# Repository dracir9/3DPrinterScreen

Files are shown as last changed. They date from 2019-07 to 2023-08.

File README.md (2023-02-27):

# 3D Printer Screen
3D Printer Screen is a 3d printer controller project based arround ESP32. The purpose of this project is to add wireless connectivity to the printer and simplify its operation through LCD and touchscreen interfaces.

**_Early development_**

## Hardware Prerequisites
This code is now targeted for use in a custom designed board which has an ESP32-S3 microcontroller, USB interface, micro SD card slot and 40-pin LCD connector. The design files in KiCad can be found here.

Follow this reference shcematic if you want to build your own board or need a pinout reference.

Pay attention to these components requirements for the project to work:
- TFT LCD display compatible with [TFT_eSPI](https://github.com/Bodmer/TFT_eSPI) library. The current version of the sowftware uses an 8-bit parallel bus but SPI can also be used to control the LCD.
- ESP32-S3 Wroom-1 with at least 8MB of SPIRAM (ESP32-S3 Wroom-2 can also be used)
- EFM8BB10F8G microcontroller

## Current features
 - [x] SD card browser
 - [x] SD card printing
 - [x] Gcode preview
 
## Screenshots
#### Main screen
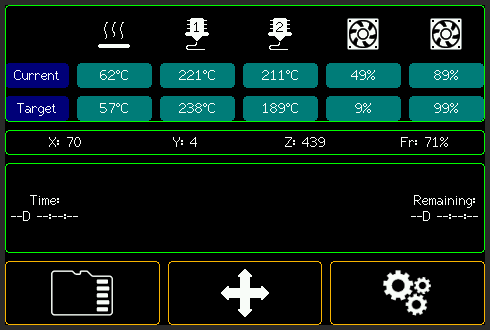
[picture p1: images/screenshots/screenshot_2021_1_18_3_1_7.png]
info

#### SD card browser
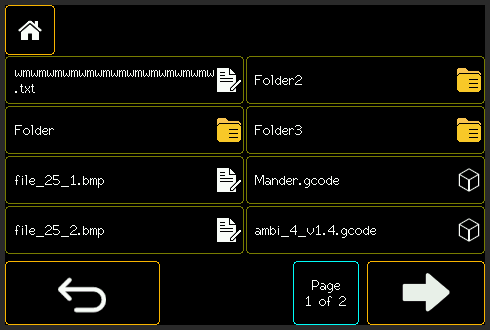
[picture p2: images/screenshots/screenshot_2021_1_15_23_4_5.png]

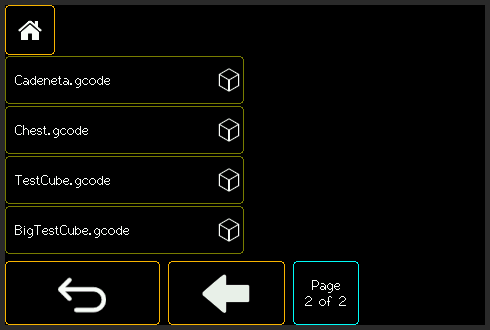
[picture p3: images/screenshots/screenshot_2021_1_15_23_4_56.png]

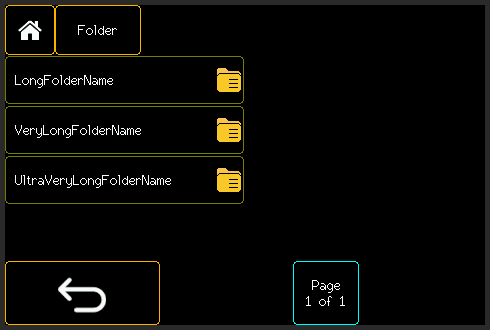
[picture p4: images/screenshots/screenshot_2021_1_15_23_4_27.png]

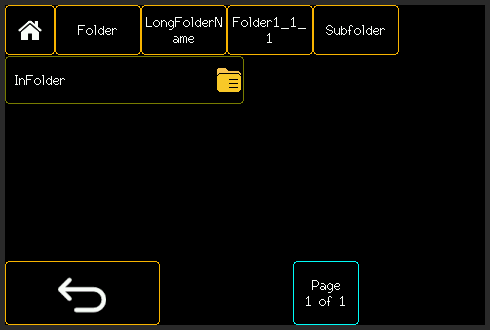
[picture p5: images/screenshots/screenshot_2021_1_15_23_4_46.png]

#### Gcode preview
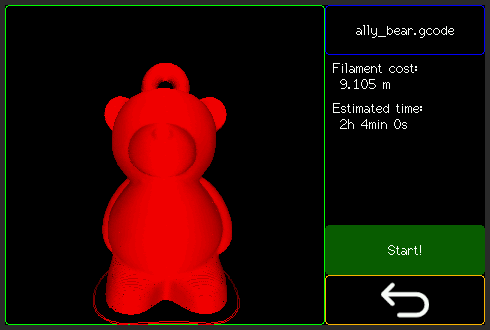
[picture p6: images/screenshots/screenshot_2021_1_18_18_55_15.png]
 Based on [this design](https://www.thingiverse.com/thing:2508515)
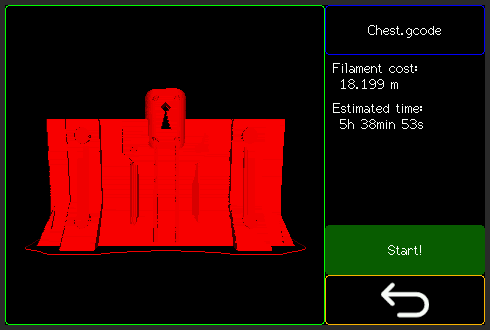
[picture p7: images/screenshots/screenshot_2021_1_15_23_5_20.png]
 Based on [this design](https://www.thingiverse.com/thing:2914080)
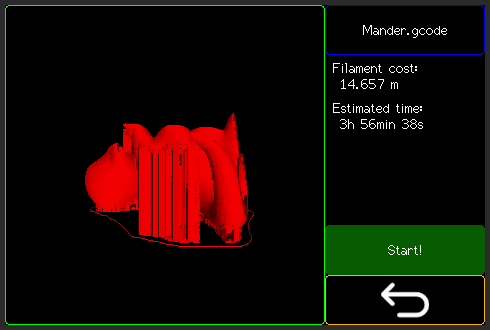
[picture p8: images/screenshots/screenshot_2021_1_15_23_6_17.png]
 Based on [this design](https://www.thingiverse.com/thing:826836)
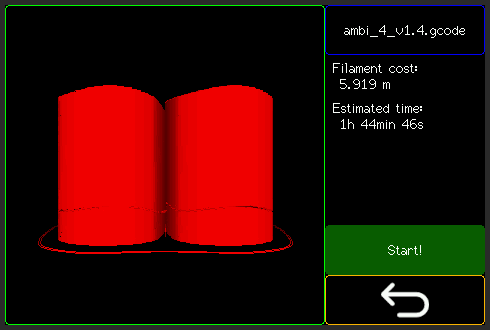
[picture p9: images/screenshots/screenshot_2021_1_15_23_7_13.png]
 Based on [this design](https://www.thingiverse.com/thing:1657791)
 
## Planned features
 - [ ] Movement, temperature, settings, file selection, etc. menus
 - [ ] SD card printing
 - [ ] WiFi printing

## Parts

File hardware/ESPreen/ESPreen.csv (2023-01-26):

Source: | D:\Users\Ricard\Documents\GitHub\3DPrinterScreen\hardware\ESPreen\ESPreen.kicad_sch
Date: | 21/01/2023 11:14:19
Tool: | Eeschema (6.0.10)
Generator: | C:\Program Files\KiCad\6.0\bin\scripting\plugins/bom_csv_grouped_by_value_with_fp.py
Component Count: | 52
Ref | Qnty | Value | Cmp name | Footprint | Description | Vendor
C1, C7, C9, C11, C13, C16, | 6 | 10uF | C | Capacitor_SMD:C_0603_1608Metric_Pad1.08x0.95mm_HandSolder | Unpolarized capacitor
C2, | 1 | 4.7uF | C | Capacitor_SMD:C_0603_1608Metric_Pad1.08x0.95mm_HandSolder | Unpolarized capacitor
C3, C4, C6, C8, C10, C15, | 6 | 100nF | C | Capacitor_SMD:C_0603_1608Metric_Pad1.08x0.95mm_HandSolder | Unpolarized capacitor
C5, C12, C14, | 3 | 1uF | C | Capacitor_SMD:C_0603_1608Metric_Pad1.08x0.95mm_HandSolder | Unpolarized capacitor
D1, D2, | 2 | LED | LED | LED_SMD:LED_0603_1608Metric_Pad1.05x0.95mm_HandSolder | Light emitting diode
D3, D4, D5, D6, D7, D8, | 6 | ESD9B3.3ST5G | ESD9B3.3ST5G | Diode_SMD:D_SOD-523 | ESD protection diode, 3.3Vrwm, SOD-923
IC1, | 1 | ESP32-S3-WROOM-1 | ESP32-S3-WROOM-1 | RF_Module:ESP32-S3-WROOM-1
J1, | 1 | USB_A | USB_A | Connector_USB:USB_A_Molex_67643_Horizontal | USB Type A connector
J2, | 1 | Conn_02x07_Odd_Even | Conn_02x07_Odd_Even | Connector_PinHeader_2.54mm:PinHeader_2x07_P2.54mm_Vertical | Generic connector, double row, 02x07, odd/even pin numbering scheme (row 1 odd numbers, row 2 even numbers), script generated (kicad-library-utils/schlib/autogen/connector/)
J3, J6, | 2 | Conn_02x03_Odd_Even | Conn_02x03_Odd_Even | Connector_PinHeader_1.27mm+:PinHeader_2x03_P1.27mm_Vertical_Shrouded | Generic connector, double row, 02x03, odd/even pin numbering scheme (row 1 odd numbers, row 2 even numbers), script generated (kicad-library-utils/schlib/autogen/connector/)
J4, | 1 | Conn_02x05_Odd_Even | Conn_02x05_Odd_Even | Connector_PinHeader_2.54mm:PinHeader_2x05_P2.54mm_Vertical | Generic connector, double row, 02x05, odd/even pin numbering scheme (row 1 odd numbers, row 2 even numbers), script generated (kicad-library-utils/schlib/autogen/connector/)
J5, | 1 | Micro_SD_Card_Det | Micro_SD_Card_Det | Connector_Card+:microSD_XunPu-F115 | Micro SD Card Socket with card detection pins
J7, | 1 | Conn_01x04 | Conn_01x04 | Connector_Molex+:Molex_SL_70553-0004_1x04_P2.54mm_Horizontal | Generic connector, single row, 01x04, script generated (kicad-library-utils/schlib/autogen/connector/)
Q1, | 1 | 2N7002 | 2N7002 | Package_TO_SOT_SMD:SOT-23 | 0.115A Id, 60V Vds, N-Channel MOSFET, SOT-23
R1, R2, | 2 | 1k | R | Resistor_SMD:R_0603_1608Metric_Pad0.98x0.95mm_HandSolder | Resistor
R3, R4, R5, R6, R7, R8, R9, R10, R12, | 9 | 10k | R | Resistor_SMD:R_0603_1608Metric_Pad0.98x0.95mm_HandSolder | Resistor
R11, | 1 | 470 | R | Resistor_SMD:R_0603_1608Metric_Pad0.98x0.95mm_HandSolder | Resistor
R13, | 1 | 0 | R | Resistor_SMD:R_0603_1608Metric_Pad0.98x0.95mm_HandSolder | Resistor
TP1, TP2, | 2 | TestPoint | TestPoint | TestPoint:TestPoint_Pad_D1.0mm | test point
U1, | 1 | LD1117S33TR_SOT223 | LD1117S33TR_SOT223 | Package_TO_SOT_SMD:SOT-223-3_TabPin2 | 800mA Fixed Low Drop Positive Voltage Regulator, Fixed Output 3.3V, SOT-223
U2, | 1 | EFM8BB10F8G-A-SOIC16 | EFM8BB10F8G-A-SOIC16 | Package_SO:SOIC-16_3.9x9.9mm_P1.27mm | 8051-compatible microcontroller, 25 MHz, 2.2 to 3.6V, 8K flash, 512B RAM, -40 to +85 C, SOIC16
U3, | 1 | USBLC6-2SC6 | USBLC6-2SC6 | Package_TO_SOT_SMD:SOT-23-6 | Very low capacitance ESD protection diode, 2 data-line, SOT-23-6
U4, | 1 | TFT43-RTP | TFT43-RTP | Connector_FFC-FPC+:Jushuo-AFC07-S40ECA-00_1x40-1MP_P0.50mm_Horizontal | 40 pin TFT-LCD Connector with resistive touch screen

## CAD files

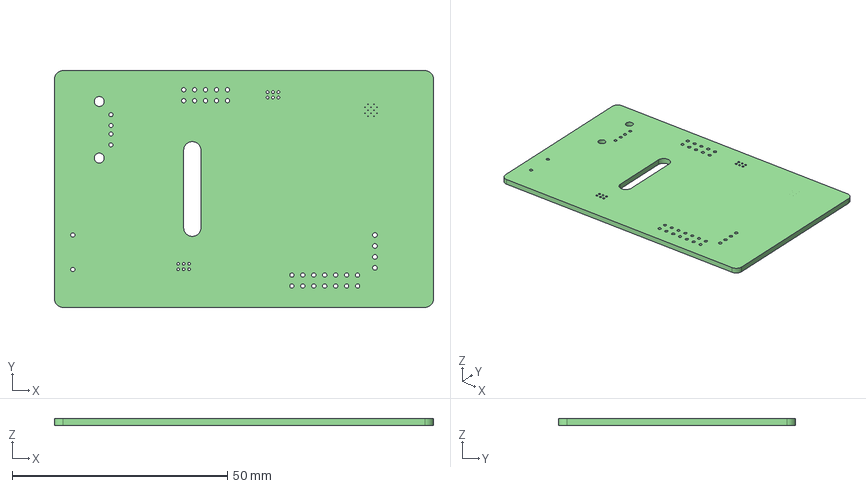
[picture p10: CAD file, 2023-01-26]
hardware/ESPreen/ESPreen.step
88.0 x 55.0 x 1.60 mm

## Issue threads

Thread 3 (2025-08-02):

what is the purpose of EFM8BB10F8G

ekaggrat, 2025-08-02:
why cant this firmware be used on a readily available esp32 board with a built in lcd and a sd card. What is the purpose of the extra microcontroller . Just asking. great project though. Is the custom pcb available somewhere?

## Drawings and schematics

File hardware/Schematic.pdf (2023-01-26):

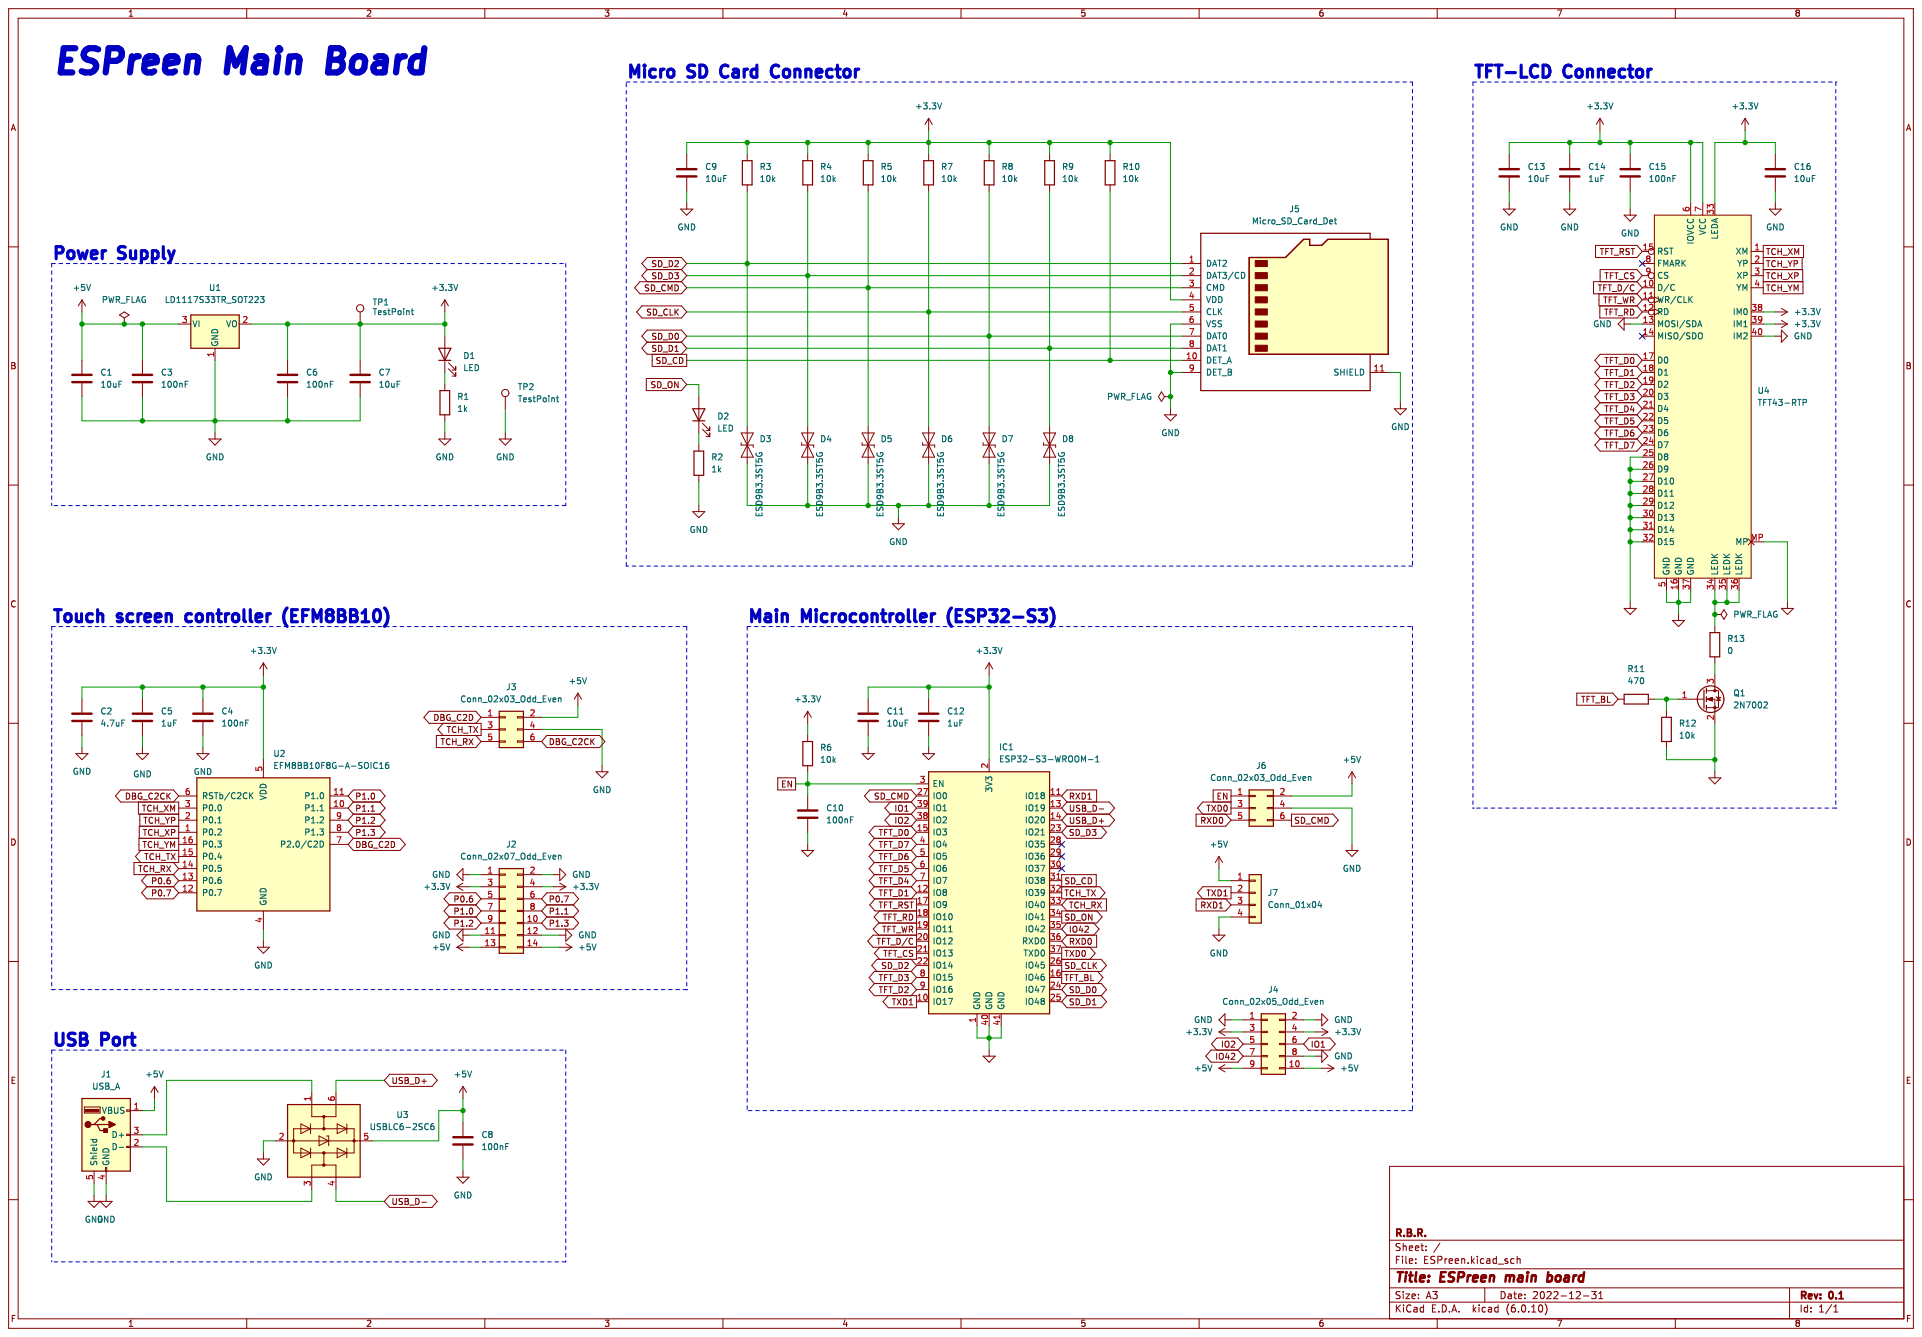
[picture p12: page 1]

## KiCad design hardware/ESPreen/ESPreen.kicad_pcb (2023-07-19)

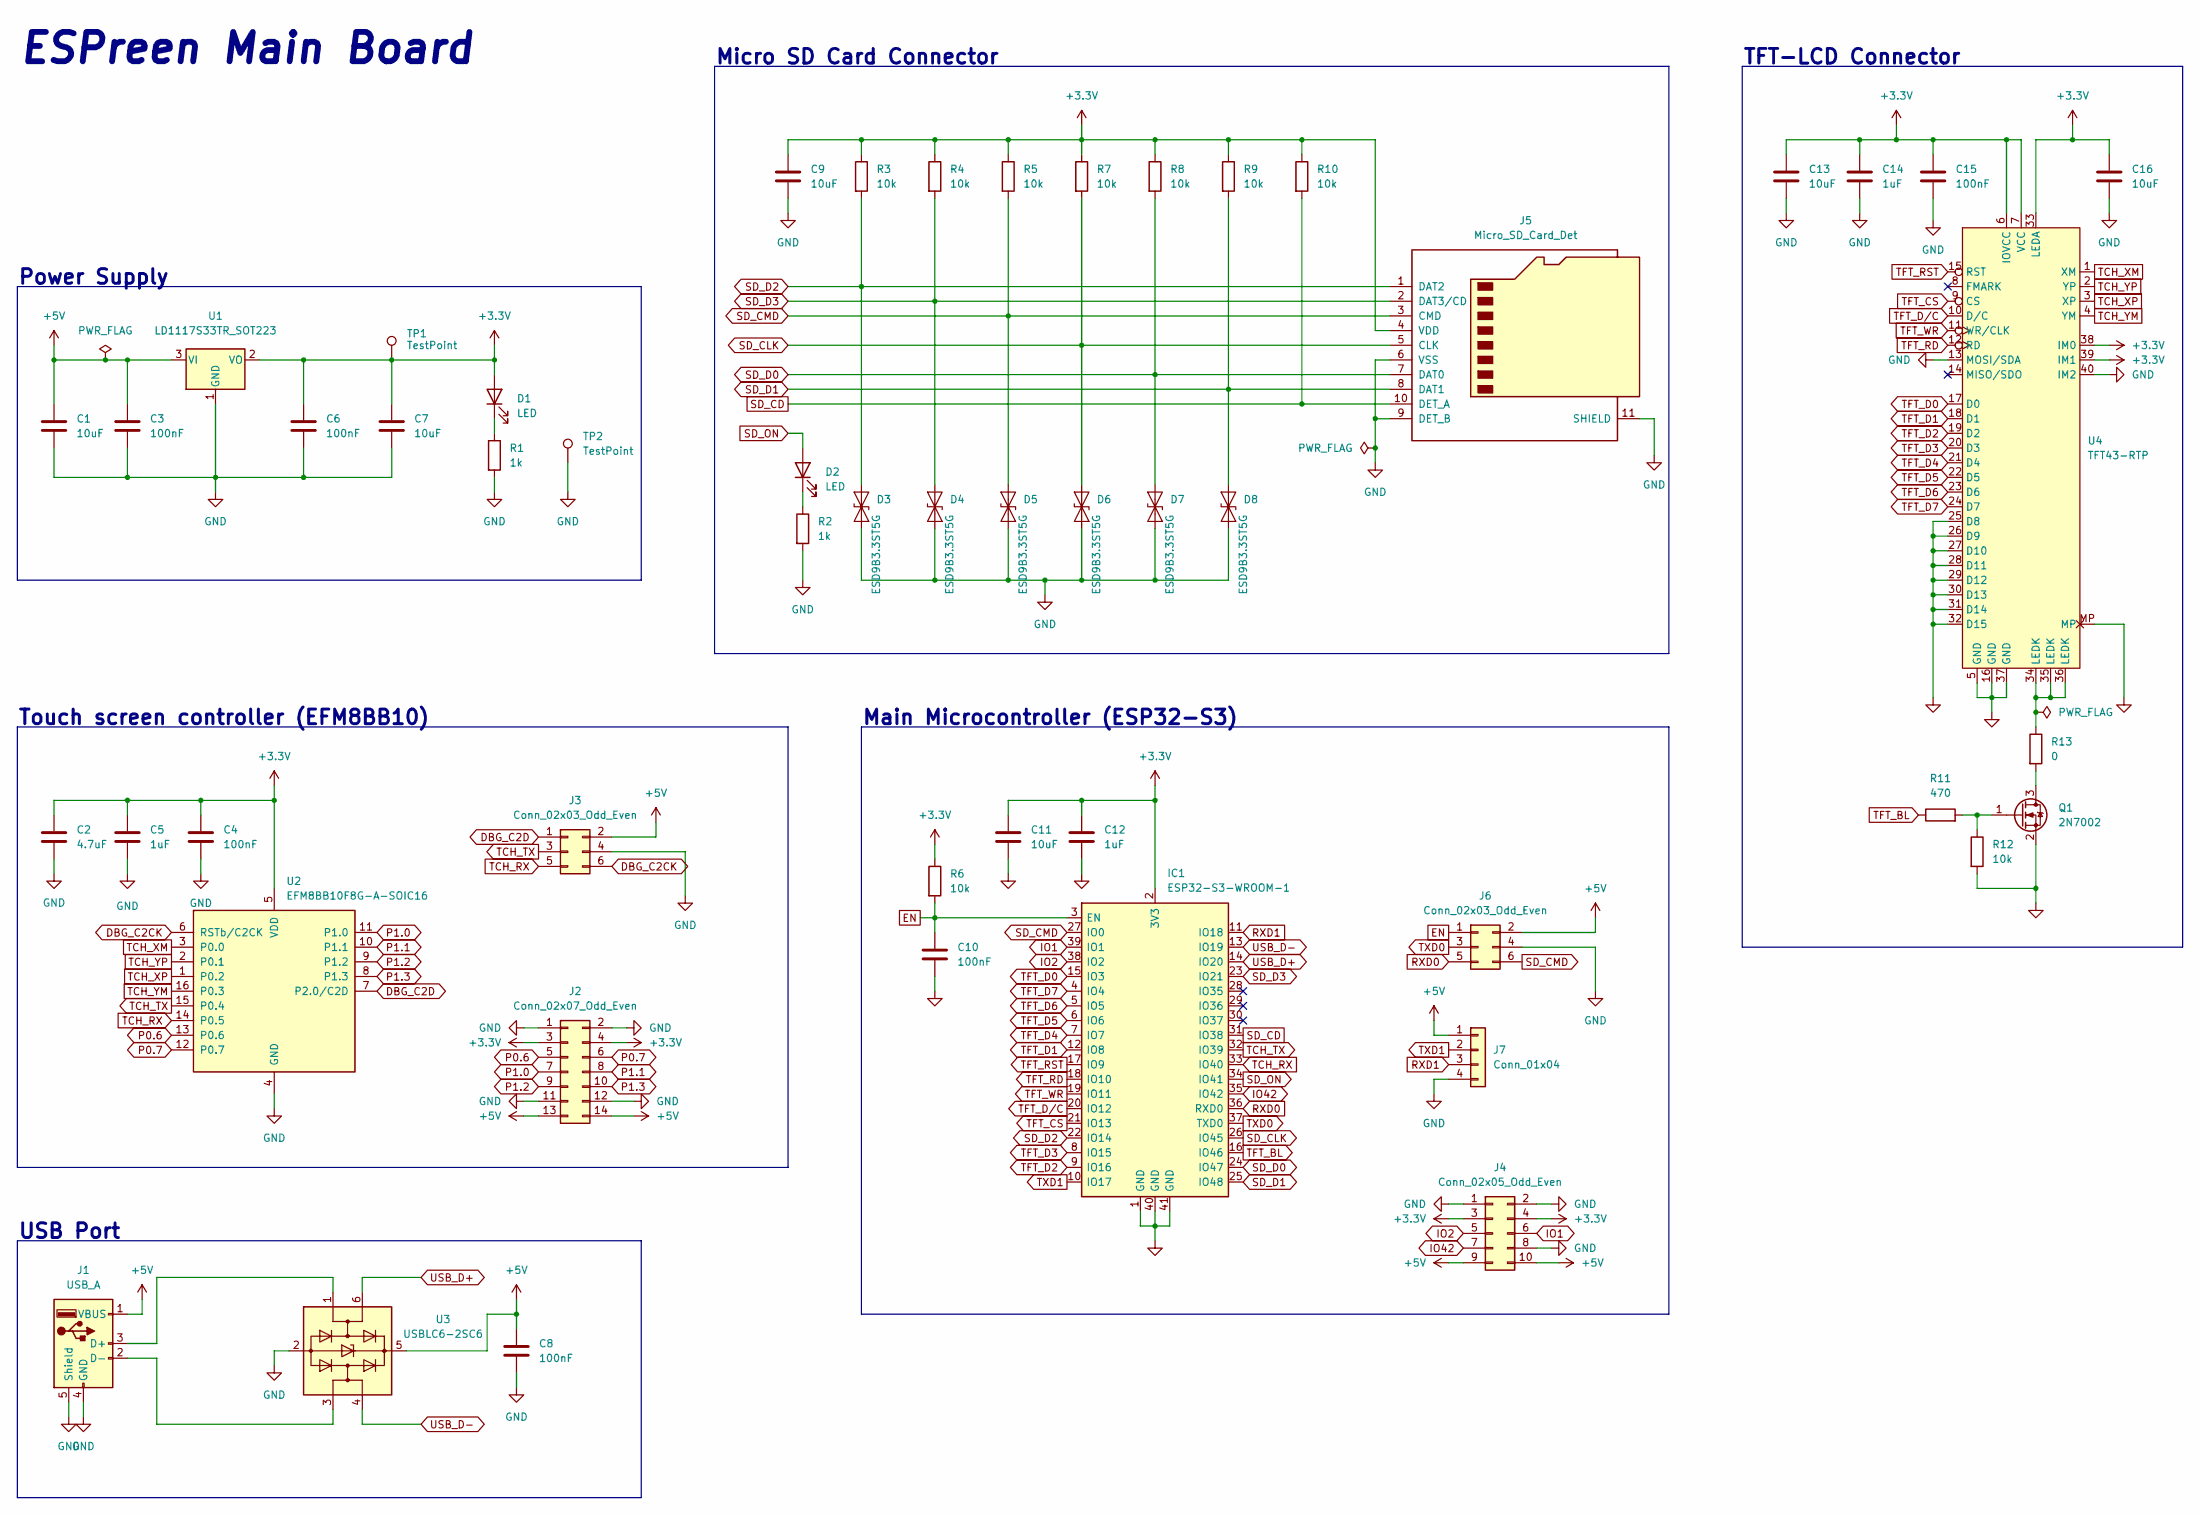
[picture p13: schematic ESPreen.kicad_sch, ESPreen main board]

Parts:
C1, C7, C9, C11, C13, C16: 10uF; C_0603_1608Metric_Pad1.08x0.95mm_HandSolder
C2: 4.7uF; C_0603_1608Metric_Pad1.08x0.95mm_HandSolder
C3, C4, C6, C8, C10, C15: 100nF; C_0603_1608Metric_Pad1.08x0.95mm_HandSolder
C5, C12, C14: 1uF; C_0603_1608Metric_Pad1.08x0.95mm_HandSolder
D1, D2: LED; LED_0603_1608Metric_Pad1.05x0.95mm_HandSolder
D3, D4, D5, D6, D7, D8: ESD9B3.3ST5G; D_SOD-523
IC1: ESP32-S3-WROOM-1; Manufacturer_Part_Number ESP32-S3-WROOM-1; Mouser Part Number 356-EP32S3WROOM1
J1: USB_A; USB_A_Molex_67643_Horizontal
J2: Conn_02x07_Odd_Even; PinHeader_2x07_P2.54mm_Vertical
J3, J6: Conn_02x03_Odd_Even; PinHeader_2x03_P1.27mm_Vertical_Shrouded
J4: Conn_02x05_Odd_Even; PinHeader_2x05_P2.54mm_Vertical
J5: Micro_SD_Card_Det; microSD_XunPu-F115
J7: Conn_01x04; Molex_SL_70553-0004_1x04_P2.54mm_Horizontal
Q1: 2N7002; SOT-23
R1, R2: 1k; R_0603_1608Metric_Pad0.98x0.95mm_HandSolder
R3, R4, R5, R6, R7, R8, R9, R10, R12: 10k; R_0603_1608Metric_Pad0.98x0.95mm_HandSolder
R11: 470; R_0603_1608Metric_Pad0.98x0.95mm_HandSolder
R13: 0; R_0603_1608Metric_Pad0.98x0.95mm_HandSolder
TP1, TP2: TestPoint; TestPoint_Pad_D1.0mm
U1: LD1117S33TR_SOT223; SOT-223-3_TabPin2
U2: EFM8BB10F8G-A-SOIC16; SOIC-16_3.9x9.9mm_P1.27mm
U3: USBLC6-2SC6; SOT-23-6
U4: TFT43-RTP; Jushuo-AFC07-S40ECA-00_1x40-1MP_P0.50mm_Horizontal

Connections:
+3.3V: C2.1, C4.1, C5.1, C6.1, C7.1, C9.1, C11.1, C12.1, C13.1, C14.1, C15.1, C16.1, D1.2 (A), IC1.2 (3V3), J2.3, J2.4, J4.3, J4.4, J5.4 (VDD), R3.1, R4.1, R5.1, R6.1, R7.1, R8.1, R9.1, R10.1, TP1.1, U1.2 (VO), U2.5 (VDD), U4.6 (IOVCC), U4.7 (VCC), U4.33 (LEDA), U4.38 (IM0), U4.39 (IM1)
+5V: C1.1, C3.1, C8.1, J1.1 (VBUS), J2.13, J2.14, J3.2, J4.9, J4.10, J6.2, J7.1, U1.3 (VI), U3.5 (VBUS)
DBG_C2CK: J3.6, U2.6 (RSTb/C2CK)
DBG_C2D: J3.1, U2.7 (P2.0/C2D)
EN: C10.1, IC1.3 (EN), J6.1, R6.2
GND: C1.2, C2.2, C3.2, C4.2, C5.2, C6.2, C7.2, C8.2, C9.2, C10.2, C11.2, C12.2, C13.2, C14.2, C15.2, C16.2, D3.1 (A1), D4.1 (A1), D5.1 (A1), D6.1 (A1), D7.1 (A1), D8.1 (A1), IC1.1 (GND), IC1.40 (GND), IC1.41 (GND), J1.4 (GND), J1.5 (Shield), J2.1, J2.2, J2.11, J2.12, J3.4, J4.1, J4.2, J4.8, J5.6 (VSS), J5.9 (DET_B), J5.11 (SHIELD), J6.4, J7.4, Q1.2 (S), R1.2, R2.2, R12.2, TP2.1, U1.1 (GND), U2.4 (GND), U3.2 (GND), U4.5 (GND), U4.13 (MOSI/SDA), U4.16 (GND), U4.25 (D8), U4.26 (D9), U4.27 (D10), U4.28 (D11), U4.29 (D12), U4.30 (D13), U4.31 (D14), U4.32 (D15), U4.37 (GND), U4.40 (IM2), U4.MP
IO1: IC1.39 (IO1), J4.6
IO2: IC1.38 (IO2), J4.5
IO42: IC1.35 (IO42), J4.7
unnamed: D1.1 (K), R1.1
unnamed: D2.1 (K), R2.1
unnamed: J1.2 (D-), U3.3 (I/O2)
unnamed: J1.3 (D+), U3.1 (I/O1)
unnamed: Q1.1 (G), R11.2, R12.1
unnamed: Q1.3 (D), R13.2
unnamed: R13.1, U4.34 (LEDK), U4.35 (LEDK), U4.36 (LEDK)
P0.6: J2.5, U2.13 (P0.6)
P0.7: J2.6, U2.12 (P0.7)
P1.0: J2.7, U2.11 (P1.0)
P1.1: J2.8, U2.10 (P1.1)
P1.2: J2.9, U2.9 (P1.2)
P1.3: J2.10, U2.8 (P1.3)
RXD0: IC1.36 (RXD0), J6.5
RXD1: IC1.11 (IO18), J7.3
SD_CD: IC1.31 (IO38), J5.10 (DET_A), R10.2
SD_CLK: D6.2 (A2), IC1.26 (IO45), J5.5 (CLK), R7.2
SD_CMD: D5.2 (A2), IC1.27 (IO0), J5.3 (CMD), J6.6, R5.2
SD_D0: D7.2 (A2), IC1.24 (IO47), J5.7 (DAT0), R8.2
SD_D1: D8.2 (A2), IC1.25 (IO48), J5.8 (DAT1), R9.2
SD_D2: D3.2 (A2), IC1.22 (IO14), J5.1 (DAT2), R3.2
SD_D3: D4.2 (A2), IC1.23 (IO21), J5.2 (DAT3/CD), R4.2
SD_ON: D2.2 (A), IC1.34 (IO41)
TCH_RX: IC1.33 (IO40), J3.5, U2.14 (P0.5)
TCH_TX: IC1.32 (IO39), J3.3, U2.15 (P0.4)
TCH_XM: U2.3 (P0.0), U4.1 (XM)
TCH_XP: U2.1 (P0.2), U4.3 (XP)
TCH_YM: U2.16 (P0.3), U4.4 (YM)
TCH_YP: U2.2 (P0.1), U4.2 (YP)
TFT_BL: IC1.16 (IO46), R11.1
TFT_CS: IC1.21 (IO13), U4.9 (CS)
TFT_D0: IC1.15 (IO3), U4.17 (D0)
TFT_D1: IC1.12 (IO8), U4.18 (D1)
TFT_D2: IC1.9 (IO16), U4.19 (D2)
TFT_D3: IC1.8 (IO15), U4.20 (D3)
TFT_D4: IC1.7 (IO7), U4.21 (D4)
TFT_D5: IC1.6 (IO6), U4.22 (D5)
TFT_D6: IC1.5 (IO5), U4.23 (D6)
TFT_D7: IC1.4 (IO4), U4.24 (D7)
TFT_D/C: IC1.20 (IO12), U4.10 (D/C)
TFT_RD: IC1.18 (IO10), U4.12 (RD)
TFT_RST: IC1.17 (IO9), U4.15 (RST)
TFT_WR: IC1.19 (IO11), U4.11 (WR/CLK)
TXD0: IC1.37 (TXD0), J6.3
TXD1: IC1.10 (IO17), J7.2
USB_D+: IC1.14 (IO20), U3.6 (I/O1)
USB_D-: IC1.13 (IO19), U3.4 (I/O2)

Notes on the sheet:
TFT-LCD Connector
Touch screen controller (EFM8BB10)
ESPreen Main Board
Micro SD Card Connector
Main Microcontroller (ESP32-S3)
Power Supply
USB Port

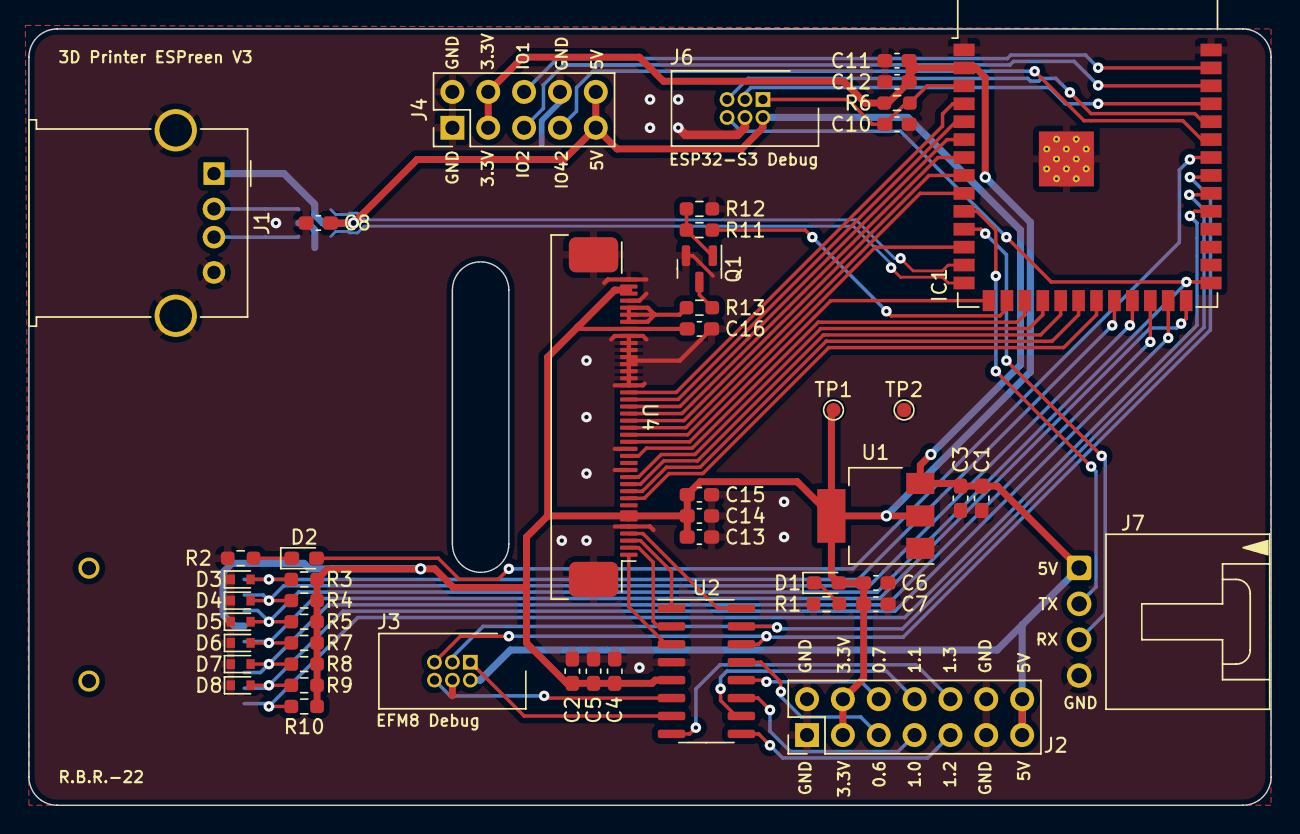
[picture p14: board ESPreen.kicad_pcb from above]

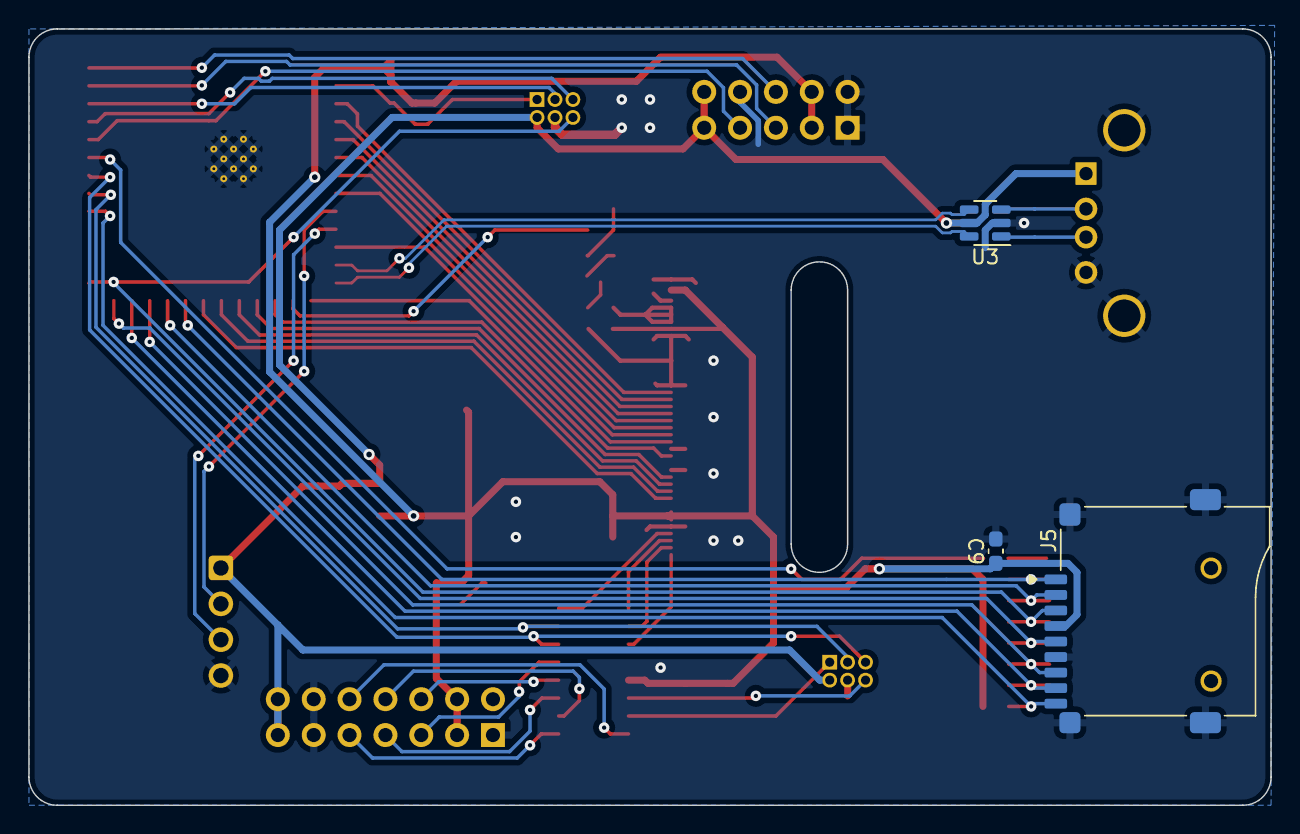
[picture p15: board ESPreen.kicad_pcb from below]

Board: 2 copper layers, 88.0 x 55.0 mm, 52 parts (3 on the bottom side), 56 nets.

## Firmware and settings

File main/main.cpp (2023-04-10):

/**
 * @file   main.c
 * @author Ricard Bitriá Ribes (https://github.com/dracir9)
 * Created Date: 21-01-2022
 * -----
 * Last Modified: 10-04-2023
 * Modified By: Ricard Bitriá Ribes
 * -----
 * @copyright (c) 2022 Ricard Bitriá Ribes
 * 
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
 * You should have received a copy of the GNU General Public License
 * along with this program.  If not, see <https://www.gnu.org/licenses/>.
 */

#include <cstdio>
#include <Arduino.h>
#include "esp_system.h"
#include "esp_spi_flash.h"
#include "dbg_log.h"
#include "esp_spiffs.h"
#include "lcdUI.h"


extern "C" void app_main(void)
{
    initArduino();

    esp_reset_reason_t reason = esp_reset_reason();
    if (reason == ESP_RST_PANIC ||
        reason == ESP_RST_INT_WDT ||
        reason == ESP_RST_TASK_WDT ||
        reason == ESP_RST_WDT ||
        reason == ESP_RST_BROWNOUT)
    {
        DBG_LOGE("System unexpected reboot! (%d)", reason);
        while (true) vTaskDelay(100);
    }

    DBG_LOGI("System ready!");

    DBG_LOGD("Free Heap at start: %d of %d\n", esp_get_free_internal_heap_size(), ESP.getHeapSize());

    // INITIALIZE SPIFFS STORAGE
    DBG_LOGI("Initializing SPIFFS");

    esp_vfs_spiffs_conf_t conf = {
      .base_path = "/spiffs",
      .partition_label = NULL,
      .max_files = 5,
      .format_if_mount_failed = false
    };

    esp_err_t ret = esp_vfs_spiffs_register(&conf);

    if (ret != ESP_OK) {
        if (ret == ESP_FAIL) {
            DBG_LOGE("Failed to mount or format filesystem");
        } else if (ret == ESP_ERR_NOT_FOUND) {
            DBG_LOGE("Failed to find SPIFFS partition");
        } else {
            DBG_LOGE("Failed to initialize SPIFFS (%s)", esp_err_to_name(ret));
        }
        return;
    }

    // INITIALIZE UI
    ret = lcdUI::instance()->begin();
    if (ret != ESP_OK)
    {
        DBG_LOGE("Failed to initialize UI. Rebooting NOW!");
        esp_restart();
    }

    lcdUI::instance()->setScreen(lcdUI::INFO_SCR);

    DBG_LOGD("Free Heap after init: %d of %d", esp_get_free_internal_heap_size(), ESP.getHeapSize());
    DBG_LOGD("Max continuous segment: %d", heap_caps_get_largest_free_block(MALLOC_CAP_INTERNAL));
    while (1)
    {
        vTaskDelay(1000);
    }
}

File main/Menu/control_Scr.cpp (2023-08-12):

/**
 * @file   control_Scr.cpp
 * @author Ricard Bitriá Ribes (https://github.com/dracir9)
 * Created Date: 10-04-2023
 * -----
 * Last Modified: 12-08-2023
 * Modified By: Ricard Bitriá Ribes
 * -----
 * @copyright (c) 2023 Ricard Bitriá Ribes
 * 
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
 * You should have received a copy of the GNU General Public License
 * along with this program.  If not, see <https://www.gnu.org/licenses/>.
 */

#include "control_Scr.h"
#include "dbg_log.h"


Control_Scr::Control_Scr(lcdUI * UI, tftLCD & tft, TchScr_Drv & ts):
    Screen(UI)
{
    tft.setTextFont(2);
    tft.setTextSize(1);
    tft.setTextPadding(0);
    tft.setTextDatum(CC_DATUM);
    
    tft.setTextColor(TFT_WHITE);

    // Bottom buttons
    tft.drawBmpSPIFFS("/spiffs/return_48.bmp", 33, 272);
    tft.drawRoundRect(0, 256, 114, 64, 4, TFT_ORANGE);
    tft.drawBmpSPIFFS("/spiffs/move_48.bmp", 155, 264);
    tft.drawRoundRect(122, 256, 114, 64, 4, TFT_ORANGE);
    tft.drawBmpSPIFFS("/spiffs/extruder_48.bmp", 277, 264);
    tft.drawRoundRect(244, 256, 114, 64, 4, TFT_ORANGE);
    tft.drawBmpSPIFFS("/spiffs/term_48.bmp", 399, 264);
    tft.drawRoundRect(366, 256, 114, 64, 4, TFT_ORANGE);

    // Joystick
    tft.drawRoundRect(0, 85 , 80, 80, 4, TFT_RED);
    tft.drawRoundRect(85, 0  , 80, 80, 4, TFT_GREEN);
    tft.drawRoundRect(85, 85 , 80, 80, 4, TFT_WHITE);
    tft.drawRoundRect(85, 170, 80, 80, 4, TFT_GREEN);
    tft.drawRoundRect(170, 0  , 80, 80, 4, TFT_BLUE);
    tft.drawRoundRect(170, 85 , 80, 80, 4, TFT_RED);
    tft.drawRoundRect(170, 170, 80, 80, 4, TFT_BLUE);
    tft.drawBmpSPIFFS("/spiffs/home_24.bmp", 113, 113);

    // Step Size
    tft.setTextDatum(CC_DATUM);
    tft.drawString("XY Step", 403, 156);
    tft.drawString("Z Step", 403, 209);

    tft.setTextFont(4);
    tft.drawRoundRect(324, 148, 50, 50, 4, TFT_CYAN);
    tft.drawString("-", 350, 174);
    tft.drawRoundRect(430, 148, 50, 50, 4, TFT_CYAN);
    tft.drawString("+", 456, 174);

    tft.drawRoundRect(324, 201 , 50, 50, 4, TFT_CYAN);
    tft.drawString("-", 350, 227);
    tft.drawRoundRect(430, 201, 50, 50, 4, TFT_CYAN);
    tft.drawString("+", 456, 227);

    // Position
    tft.setTextFont(2);
    tft.setTextSize(1);
    tft.setTextPadding(0);
    tft.setTextDatum(CC_DATUM);
    tft.drawRoundRect(280, 0, 200, 50, 4, TFT_GREEN);
    tft.drawString("X", 313, 16);
    tft.drawString("Y", 380, 16);
    tft.drawString("Z", 447, 16);

    tft.setTextPadding(60);
    tft.drawString(String(999.0f), 313, 32);
    tft.drawString(String(999.0f), 380, 32);
    tft.drawString(String(999.0f), 447, 32);

    // Home XY only
    tft.drawRoundRect(315, 59, 80, 80, 4, TFT_WHITE);
    tft.drawBmpSPIFFS("/spiffs/home_24.bmp", 343, 87);
    tft.drawString("Home XY", 355, 125);

    // Home Z only
    tft.drawRoundRect(400, 59, 80, 80, 4, TFT_WHITE);
    tft.drawBmpSPIFFS("/spiffs/home_24.bmp", 428, 87);
    tft.drawString("Home Z", 440, 125);

    Button tmpBut;
    tmpBut.id = 0;
    tmpBut.xmin = 0;
    tmpBut.xmax = 114;
    tmpBut.ymin = 256;
    tmpBut.ymax = 320;
    tmpBut.enReleaseEv = true;
    
    ts.setButton(&tmpBut); // Back to Info screen

    tmpBut.id = 2;
    tmpBut.xmin = 85;
    tmpBut.xmax = 165;
    tmpBut.ymin = 85;
    tmpBut.ymax = 165;
    tmpBut.enPressEv = true;
    tmpBut.enHoldEv = true;
    tmpBut.enReleaseEv = true;

    ts.setButton(&tmpBut); // Home all axis

    tmpBut.id = 3;
    tmpBut.xmin = 0;
    tmpBut.xmax = 80;
    tmpBut.ymin = 85;
    tmpBut.ymax = 165;
    tmpBut.enPressEv = true;
    tmpBut.enHoldEv = true;
    tmpBut.enReleaseEv = true;

    ts.setButton(&tmpBut); // Move X-

    tmpBut.id = 4;
    tmpBut.xmin = 170;
    tmpBut.xmax = 250;
    tmpBut.ymin = 85;
    tmpBut.ymax = 165;
    tmpBut.enPressEv = true;
    tmpBut.enHoldEv = true;
    tmpBut.enReleaseEv = true;

    ts.setButton(&tmpBut); // Move X+

    tmpBut.id = 5;
    tmpBut.xmin = 85;
    tmpBut.xmax = 165;
    tmpBut.ymin = 170;
    tmpBut.ymax = 250;
    tmpBut.enPressEv = true;
    tmpBut.enHoldEv = true;
    tmpBut.enReleaseEv = true;

    ts.setButton(&tmpBut); // Move Y-

    tmpBut.id = 6;
    tmpBut.xmin = 85;
    tmpBut.xmax = 165;
    tmpBut.ymin = 0;
    tmpBut.ymax = 80;
    tmpBut.enPressEv = true;
    tmpBut.enHoldEv = true;
    tmpBut.enReleaseEv = true;

    ts.setButton(&tmpBut); // Move Y+

    tmpBut.id = 7;
    tmpBut.xmin = 170;
    tmpBut.xmax = 250;
    tmpBut.ymin = 170;
    tmpBut.ymax = 250;
    tmpBut.enPressEv = true;
    tmpBut.enHoldEv = true;
    tmpBut.enReleaseEv = true;

    ts.setButton(&tmpBut); // Move Z-

    tmpBut.id = 8;
    tmpBut.xmin = 170;
    tmpBut.xmax = 250;
    tmpBut.ymin = 0;
    tmpBut.ymax = 80;
    tmpBut.enPressEv = true;
    tmpBut.enHoldEv = true;
    tmpBut.enReleaseEv = true;

    ts.setButton(&tmpBut); // Move Z+

    tmpBut.id = 9;
    tmpBut.xmin = 324;
    tmpBut.xmax = 374;
    tmpBut.ymin = 164;
    tmpBut.ymax = 214;
    tmpBut.enPressEv = false;
    tmpBut.enHoldEv = false;
    tmpBut.enReleaseEv = true;

    ts.setButton(&tmpBut); // Step -

    tmpBut.id = 10;
    tmpBut.xmin = 430;
    tmpBut.xmax = 480;
    tmpBut.ymin = 164;
    tmpBut.ymax = 214;
    tmpBut.enPressEv = false;
    tmpBut.enHoldEv = false;
    tmpBut.enReleaseEv = true;

    ts.setButton(&tmpBut); // Step +

    tmpBut.id = 11;
    tmpBut.xmin = 324;
    tmpBut.xmax = 374;
    tmpBut.ymin = 217;
    tmpBut.ymax = 257;
    tmpBut.enPressEv = false;
    tmpBut.enHoldEv = false;
    tmpBut.enReleaseEv = true;

    ts.setButton(&tmpBut); // Z Step -

    tmpBut.id = 12;
    tmpBut.xmin = 430;
    tmpBut.xmax = 480;
    tmpBut.ymin = 217;
    tmpBut.ymax = 257;
    tmpBut.enPressEv = false;
    tmpBut.enHoldEv = false;
    tmpBut.enReleaseEv = true;

    ts.setButton(&tmpBut); // Z Step +

    tmpBut.id = 13;
    tmpBut.xmin = 244;
    tmpBut.xmax = 358;
    tmpBut.ymin = 256;
    tmpBut.ymax = 320;
    tmpBut.enPressEv = false;
    tmpBut.enHoldEv = false;
    tmpBut.enReleaseEv = true;

    ts.setButton(&tmpBut); // Extruder control

    tmpBut.id = 14;
    tmpBut.xmin = 366;
    tmpBut.xmax = 480;
    tmpBut.ymin = 256;
    tmpBut.ymax = 320;
    tmpBut.enPressEv = false;
    tmpBut.enHoldEv = false;
    tmpBut.enReleaseEv = true;

    ts.setButton(&tmpBut); // Temperature control

    tmpBut.id = 15;
    tmpBut.xmin = 315;
    tmpBut.xmax = 395;
    tmpBut.ymin = 59;
    tmpBut.ymax = 139;
    tmpBut.enPressEv = false;
    tmpBut.enHoldEv = false;
    tmpBut.enReleaseEv = true;

    ts.setButton(&tmpBut); // Home XY

    tmpBut.id = 16;
    tmpBut.xmin = 400;
    tmpBut.xmax = 480;
    tmpBut.ymin = 59;
    tmpBut.ymax = 139;
    tmpBut.enPressEv = false;
    tmpBut.enHoldEv = false;
    tmpBut.enReleaseEv = true;

    ts.setButton(&tmpBut); // Home Z
}
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

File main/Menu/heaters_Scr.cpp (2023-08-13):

/**
 * @file   heaters_Scr.cpp
 * @author Ricard Bitriá Ribes (https://github.com/dracir9)
 * Created Date: 12-08-2023
 * -----
 * Last Modified: 13-08-2023
 * Modified By: Ricard Bitriá Ribes
 * -----
 * @copyright (c) 2023 Ricard Bitriá Ribes
 * 
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
 * You should have received a copy of the GNU General Public License
 * along with this program.  If not, see <https://www.gnu.org/licenses/>.
 */

#include "heaters_Scr.h"
#include "dbg_log.h"


Heaters_Scr::Heaters_Scr(lcdUI * UI, tftLCD & tft, TchScr_Drv & ts):
    Screen(UI)
{
    tft.setTextFont(2);
    tft.setTextSize(1);
    tft.setTextPadding(0);
    tft.setTextDatum(CC_DATUM);
    tft.setTextColor(TFT_WHITE);

    // Bottom buttons
    tft.drawBmpSPIFFS("/spiffs/return_48.bmp", 33, 272);
    tft.drawRoundRect(0, 256, 114, 64, 4, TFT_ORANGE);

    tft.drawBmpSPIFFS("/spiffs/move_48.bmp", 155, 264);
    tft.drawRoundRect(122, 256, 114, 64, 4, TFT_ORANGE);

    tft.drawBmpSPIFFS("/spiffs/extruder_48.bmp", 277, 264);
    tft.drawRoundRect(244, 256, 114, 64, 4, TFT_ORANGE);

    tft.drawBmpSPIFFS("/spiffs/term_48.bmp", 399, 264);
    tft.drawRoundRect(366, 256, 114, 64, 4, TFT_ORANGE);

    // Step Size
    tft.drawString("Step", 455, 120);

    tft.setTextFont(4);
    tft.drawRoundRect(430, 51, 50, 50, 4, TFT_CYAN);
    tft.drawString("+", 456, 76);
    tft.drawRoundRect(430, 155, 50, 50, 4, TFT_CYAN);
    tft.drawString("-", 456, 180);

    Button tmpBut;
    tmpBut.id = 0;
    tmpBut.xmin = 0;
    tmpBut.xmax = 114;
    tmpBut.ymin = 256;
    tmpBut.ymax = 320;
    tmpBut.enReleaseEv = true;
    
    ts.setButton(&tmpBut); // Back to Info screen

    tmpBut.id = 1;
    tmpBut.xmin = 122;
    tmpBut.xmax = 236;
    tmpBut.ymin = 256;
    tmpBut.ymax = 320;
    tmpBut.enReleaseEv = true;

    ts.setButton(&tmpBut); // Move control

    tmpBut.id = 2;
    tmpBut.xmin = 244;
    tmpBut.xmax = 358;
    tmpBut.ymin = 256;
    tmpBut.ymax = 320;
    tmpBut.enReleaseEv = true;

    ts.setButton(&tmpBut); // Extruder control

    tmpBut.id = 3;
    tmpBut.xmin = 430;
    tmpBut.xmax = 480;
    tmpBut.ymin = 51;
    tmpBut.ymax = 101;
    tmpBut.enReleaseEv = true;

    ts.setButton(&tmpBut); // Step -

    tmpBut.id = 4;
    tmpBut.xmin = 430;
    tmpBut.xmax = 480;
    tmpBut.ymin = 155;
    tmpBut.ymax = 205;
    tmpBut.enReleaseEv = true;

    ts.setButton(&tmpBut); // Step +

    // Extruders
    numTools = _printer->getToolNum();

    if (numTools == 0)
        numTools = 2;

    float spacing = ((480.0f - 50.0f) - (numTools+1)*buttSize) / (numTools + 2);
    
    tft.setTextFont(2);
    for (int32_t i = 0; i <= numTools; i++)
    {
        if (i < numTools)
        {        
            tft.drawRoundRect(spacing*(i+1) + buttSize*i, 0, buttSize, buttSize, 4, TFT_WHITE);
            tft.drawBmpSPIFFS("/spiffs/arrowT_48.bmp", spacing*(i+1) + buttSize*i +20, 16);

            tft.drawBmpSPIFFS("/spiffs/extruder_32.bmp", spacing*(i+1) + buttSize*i +24, 112);
            tft.setTextColor(TFT_BLACK);
            tft.drawString(String(i+1), spacing*(i+1) + buttSize*i +40, 120);
            tft.setTextColor(TFT_WHITE);
            tft.drawString("000.0", spacing*(i+1) + buttSize*i +40, 155);

            tft.drawRoundRect(spacing*(i+1) + buttSize*i, 170, buttSize, buttSize, 4, TFT_WHITE);
            tft.drawBmpSPIFFS("/spiffs/arrowB_48.bmp", spacing*(i+1) + buttSize*i +20, 186);
        }
        else
        {
            tft.drawRoundRect(spacing*(i+1) + buttSize*i, 0, buttSize, buttSize, 4, TFT_WHITE);
            tft.drawBmpSPIFFS("/spiffs/arrowT_48.bmp", spacing*(i+1) + buttSize*i +20, 16);

            tft.drawBmpSPIFFS("/spiffs/heatbed_32.bmp", spacing*(i+1) + buttSize*i +24, 112);
            tft.setTextColor(TFT_WHITE);

            tft.drawString("000.0", spacing*(i+1) + buttSize*i +40, 155);

            tft.drawRoundRect(spacing*(i+1) + buttSize*i, 170, buttSize, buttSize, 4, TFT_WHITE);
            tft.drawBmpSPIFFS("/spiffs/arrowB_48.bmp", spacing*(i+1) + buttSize*i +20, 186);
        }

        tmpBut.id = 5+i*2;
        tmpBut.xmin = spacing*(i+1) + buttSize*i;
        tmpBut.xmax = spacing*(i+1) + buttSize*i + buttSize;
        tmpBut.ymin = 0;
        tmpBut.ymax = 80;
        tmpBut.enReleaseEv = true;

        ts.setButton(&tmpBut); // Step -

        tmpBut.id = 6+i*2;
        tmpBut.xmin = spacing*(i+1) + buttSize*i;
        tmpBut.xmax = spacing*(i+1) + buttSize*i + buttSize;
        tmpBut.ymin = 170;
        tmpBut.ymax = 250;
        tmpBut.enReleaseEv = true;

        ts.setButton(&tmpBut); // Step +
    }
}

void Heaters_Scr::update(uint32_t deltaTime, TchScr_Drv &ts)
{
    esp_err_t ret = ESP_OK;

    if (ret != ESP_OK)
    {
        DBG_LOGE("Failed to move the toolhead: %s", esp_err_to_name(ret));
    }
}

void Heaters_Scr::render(tftLCD &tft)
{
    tft.setTextSize(1);
    tft.setTextDatum(CC_DATUM);

    tft.setTextFont(2);
    tft.setTextPadding(50);
    tft.setTextColor(TFT_WHITE, TFT_BLACK);
    tft.drawString(String(stepSize, 1), 455, 136);

    float spacing = ((480.0f - 50.0f) - (numTools+1)*buttSize) / (numTools + 2);

    String tempTxt;
    float temperature;
    for (int32_t i = 0; i <= numTools; i++)
    {
        if (i < numTools)
        {            
            tempTxt = String(_printer->getTarToolTemp(i), 0);
            temperature = _printer->getTarToolTemp(i);
        }
        else
        {
            tempTxt = String(_printer->getTarBedTemp(), 0);
            temperature = _printer->getTarBedTemp();
        }
        
        tempTxt += ' ';
        tempTxt += _printer->getTempUnit();

        tft.setTextColor(TFT_WHITE, TFT_BLACK);
        tft.drawString(tempTxt, spacing*(i+1) + buttSize*i +40, 155);

        if (temperature < 150.0f)
            tft.setTextColor(TFT_CYAN, TFT_BLACK);
        else if (temperature < 200.0f)
            tft.setTextColor(TFT_WHITE, TFT_BLACK);
        else
            tft.setTextColor(TFT_ORANGE, TFT_BLACK);

        tempTxt = String(temperature, 0);
        tempTxt += ' ';
        tempTxt += _printer->getTempUnit();
        tft.drawString(tempTxt, spacing*(i+1) + buttSize*i + 40, 100);
    }
}
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

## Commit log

2019-07-02 getTxtBounds and getSize udate
    Overloaded get TextSize function to optimize for some use cases and fixed the vertical box getSize function
    [lcdUI.cpp, lcdUI.h, main.cpp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]
2019-07-03 Fixed and improved screen load/update
    [lcdUI.cpp, lcdUI.h, main.cpp]
2019-07-05 Added max framerate and allowed text updates
    Cleaned up some code.
    Added debugging boxes arround widgets boundaries
2019-07-17 Added print with background
2019-07-17 Improved printBg efficiency
2019-07-21 Switch to TFT_eSPI library
    [Configuration.h]
2019-07-23 Fixed new library compatibility issues
    [lcdUI.cpp, lcdUI.h, main.cpp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]
2019-07-23 Code cleanup
    - Removed old commented codes
    - Added some function descriptions
    - Improved sprite usage
    [Configuration.h]
2019-09-01 Split widgets
    Moved widget classes into its own header and source file to improve organization
    [Configuration.h]
2019-09-02 Created class for each menu screen
    [Configuration.h]
2019-09-09 Move menu classes into dedicated files
    [Configuration.h]
2019-11-07 Minor code corrections
    Improved code correctness and made small optimizations in some loops
    [info_w.cpp, lcdUI.cpp, lcdUI.h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]
2019-11-15 TouchScreen improvement
    Now we use registers to change pin states(it is faster)
2020-10-01 Change Serial.print to printf() function
2020-10-04 Update logging to ESP_LOG
    [Configuration.h]
2020-10-30 Switched render routine to a RTOS task
2020-11-02 Extend SPI mutex and thread safety improvements
2020-11-04 Fix touch events registration
    [lcdUI.cpp, lcdUI.h]
2020-11-04 Add visual debugging for touch input
    [Configuration.h]
2020-12-15 Added icons and fixed rendering bug
    [fileBrowser_Scr.cpp]
2020-12-26 Created shorter names for common vector types
    [fileBrowser_Scr.cpp, lcdUI.h, tftLCD.cpp]
2021-01-03 Changed fps to minimum frame time
2021-01-03 Frame Time accessor
2021-01-03 Add print information
2021-01-04 Restore old screen prototype
2021-01-06 Add sd card button and code cleanup
2021-01-08 Fix rendering bug and raise TFT library version
    [fileBrowser_Scr.cpp]
2021-01-11 Add utility to print screen to file through serial
2021-01-12 Utilities can now be enabled independently
    [Configuration.h]
2021-01-12 Fix screen refresh rate bug
    [lcdUI.cpp]
2021-01-16 Gcode rendering worktime dependent on framerate
2021-01-16 Configurable heatbeds, extruder and fans number
2021-01-18 Add heatbed, extruder and fan icons
2021-03-11 Configure code for new board
2021-03-16 Fix SPI management problem
    [lcdUI.cpp]
2021-03-16 Implement SD card detect pin
2021-03-16 Read touch on interrupt
2022-01-21 Switch to ESP-IDF
    [Configuration.h]
2022-01-22 Configure device
    [partitions_two_ota_SPIFFS.csv]
2022-01-22 Add previous code
    [Configuration.h]
2022-01-22 partial update touch driver and fix compile errors
    [fileBrowser_Scr.cpp, lcdUI.cpp, lcdUI.h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]
2022-01-31 Update touch driver
2022-01-31 Touch driver minor fix
2022-02-06 Update touch driver: Fix get event deadlock
2022-02-06 Update function calls to handle new touch driver
2022-02-12 Implement buttons in file browser
2022-02-12 Update TFT driver
2022-02-16 Switch to new render engine
2022-02-20 Fix render engine state issues
    [fileBrowser_Scr.cpp]
2022-02-26 Optimize camera position calculation
2022-03-06 Add print info, fix bugs and rename preview screen
    [lcdUI.cpp]
2022-03-12 Bug fix and improved camera orientation system
2022-03-12 Fix camera rotation
2022-03-14 Add print info to render cache Add cases to comment parser
2022-03-26 Alternative filament lenght calculation
2022-04-09 Update to new board
2022-04-10 Add project configuration options to idf menu
    [Configuration.h]
2022-04-11 Add harware schematic
2022-04-12 Update touch library and fix some bugs
    [fileBrowser_Scr.cpp, info_Scr.cpp, lcdUI.cpp]
2022-04-15 Setup display backlight PWM and control menu
2022-05-02 Add printer class and uart communication
2022-05-08 Update Arduino component to 2.0.3
2022-06-09 Fix serial line separation and add parse options
    [lcdUI.cpp, printer.cpp]
2022-06-11 Allocate dynamic extruder fields
2022-06-11 Parse temperatures
2022-06-11 Conver printer to singleton
2022-06-11 Display real temperatures
2022-06-12 Send gcode file to printer
2022-06-24 Create print screen
2022-06-24 Handle printer state in preview_Scr
2022-06-24 Start printing on print_Scr
2022-11-30 Create KiCad project
    [ESPreen.kicad_pcb, ESPreen.kicad_sch]
2023-01-26 Update to finished board
    [ESPreen-B_Mask.gbs, ESPreen-B_Paste.gbp, ESPreen-B_Silkscreen.gbo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]
2023-02-20 Update PCB schematic
2023-02-20 Minor pcb update
    [ESPreen.kicad_pcb]
2023-02-20 Switch to esp32s3
2023-02-20 Update touch driver library
2023-02-25 Update printer UART port and pins
2023-02-25 Centralize pin assignments
2023-02-25 Stop booting on certain reset reasons
    [main.cpp]
2023-02-25 Rename again with lower case
2023-02-26 Update SD card driver with new pins
2023-03-05 Remove UART Tx Task
2023-03-10 Rework code for sending commands
    [printer.cpp]
2023-03-10 Switch to std::vector for easier memory management
2023-03-11 Switch to managed pointers
2023-03-11 Switch to managed fstream
2023-04-16 Add touch buttons and UI layout update
2023-04-16 Add button text. Fix button glitches
    [control_Scr.cpp]
2023-04-18 Implement toolhead movement
2023-06-03 Update KiCad version
2023-07-19 Update kicad files
    [ESPreen.kicad_pcb, ESPreen.kicad_sch]
2023-07-24 Display four bottom buttons
2023-08-02 Add extruder control screen
2023-08-08 Add icons to bottom buttons
2023-08-10 Add position display and more homing options
2023-08-10 Add homing buttons
2023-08-10 Add function to home printer axes
2023-08-10 Send home cmd to printer
2023-08-12 Adjust extruder screen layout
2023-08-12 Add function to move extruder
2023-08-12 Implement extruder screen logic
2023-08-12 Add temperature display
2023-08-12 Add new heater screen
2023-08-12 Integrate heater screen with other screens
2023-08-13 Add functions to set the temperature
2023-08-13 Adjust heater screen layout and logic
2023-08-30 Add full screen frame buffer
2023-08-30 Add case in printer serial parser

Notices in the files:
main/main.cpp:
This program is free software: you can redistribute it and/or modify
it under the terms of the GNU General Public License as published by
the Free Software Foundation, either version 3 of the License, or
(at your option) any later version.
